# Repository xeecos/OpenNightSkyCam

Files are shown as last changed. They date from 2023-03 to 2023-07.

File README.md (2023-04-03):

# Open Night Sky Cam
Open Night Sky Cam is a long exposure time camera based on ESP32-S3.

## Features
* Based On ESP32-S3-Wroom-1 Module with 8MB Flash and 8MB PSRAM
* Long Exposure Time
* TF card supported by SDMMC or SdFat Library
* U-Disk Mode, USB 2.0 HighSpeed Write and Read Files
* C-Mount, also Support M12 Lens and 1.25 Inch Telescope Mount with adapter
* USB Serial Mode

## Architecture
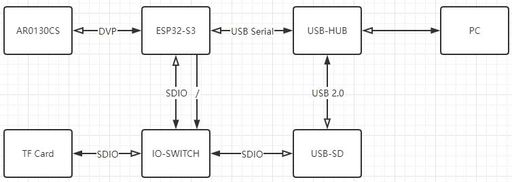
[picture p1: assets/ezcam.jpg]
architecture ezcam_architecture


## PCB
* Main PCB Project: https://oshwlab.com/flashindream/opennightskycam
* Sensor PCB Project: https://oshwlab.com/flashindream/ar0130-dvp
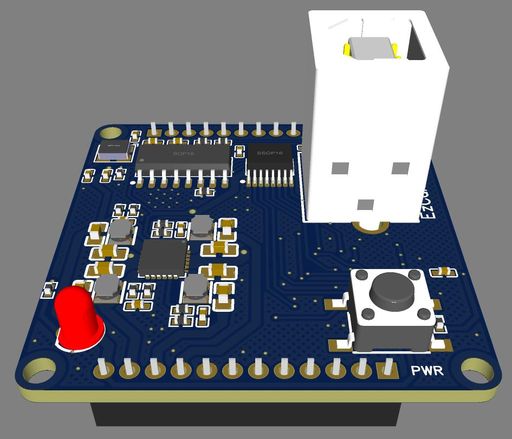
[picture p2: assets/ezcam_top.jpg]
pcb ezcam_top

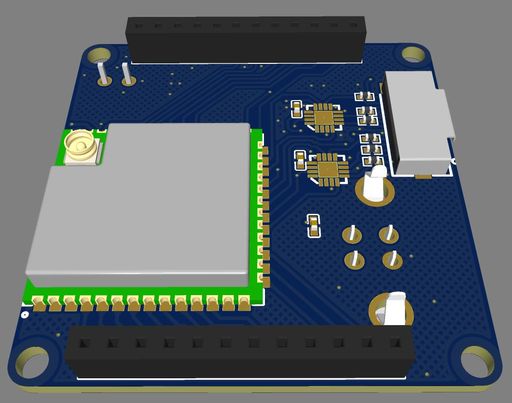
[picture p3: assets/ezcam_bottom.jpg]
pcb ezcam_bottom

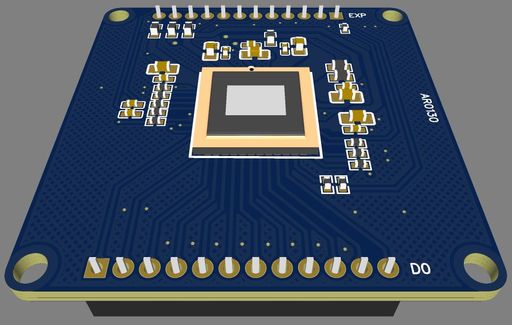
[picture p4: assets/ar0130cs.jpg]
pcb ar0130cs


## Mechanical
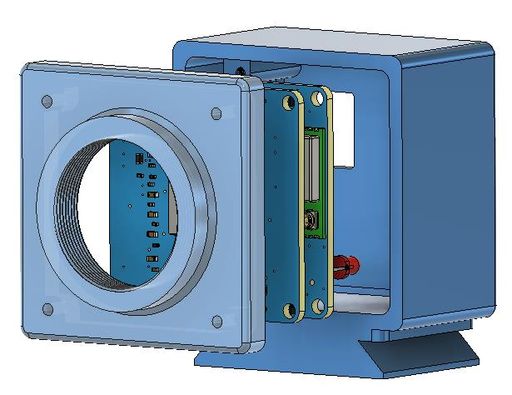
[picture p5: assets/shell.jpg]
shell


## Firmware
* install VSCode and Platformio
* download and open the firmware source code by VSCode
* copy the "esp32-s3-wroom-1.json" to ~/.platformio/platforms/espressif32/boards
* compile the code
* build and upload the filesystem image for web

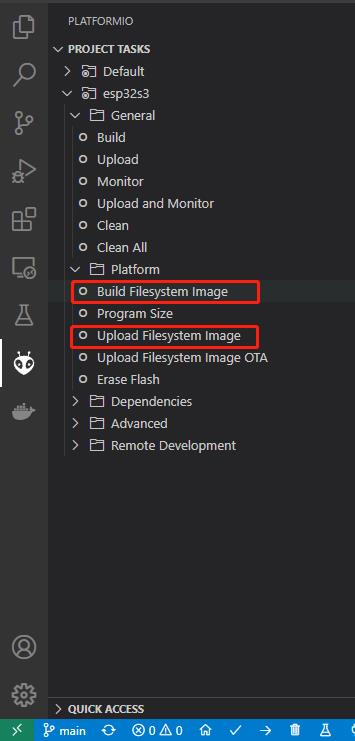
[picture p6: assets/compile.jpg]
compile


## How To Use
* plug in USB cable to the cam.
* connect "Night-Sky" ssid without password by WiFi
* open http://192.168.43.1/index.html on your browser
* close the U-DISK mode on Setting tab
* then preview it 

## Video
* https://www.youtube.com/watch?v=hJdsUjagThk
* https://www.youtube.com/watch?v=0wduta1NCjs
* https://www.youtube.com/watch?v=QMlR2NVDoeQ

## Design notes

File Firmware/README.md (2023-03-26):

# Open Night Sky Cam
# 蓝牙连接
### 查询名称和ip
### 配置WiFi网络
### 修改名称
# WiFi连接
### 查询状态
 * 版本号
 * 任务状态
 * 时间
### 查询SD文件列表
### 获取最新照片
### 设置参数
 * 拍摄参数
 * 时间
### 设置任务
### 开始任务
### 暂停任务
### 继续任务
# OTA升级

### Upload Firmware
esptool.exe --chip esp32s3 --port "COM5" --baud 921600  --before default_reset --after hard_reset write_flash  -z --flash_mode dio --flash_freq 80m --flash_size 8MB 0x0 ".pio//build//esp32s3//bootloader.bin" 0x8000 ".pio//build//esp32s3//partitions.bin" 0x10000 ".pio//build//esp32s3//firmware.bin"

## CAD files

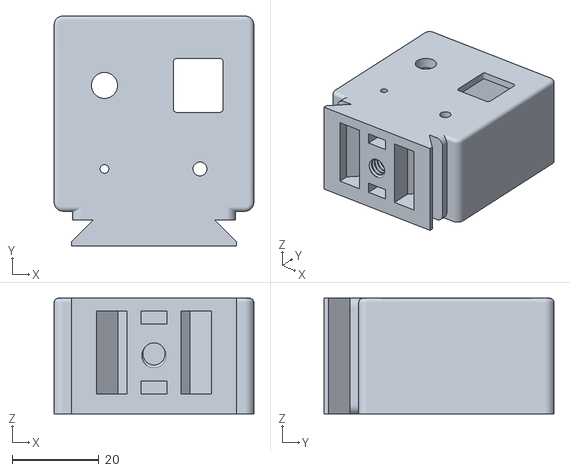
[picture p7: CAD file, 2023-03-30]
Mechanical/bottom.stl
46.0 x 53.0 x 26.7

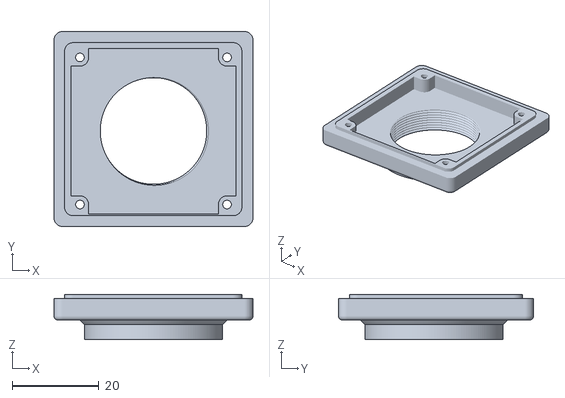
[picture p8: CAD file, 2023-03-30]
Mechanical/top.stl
46.0 x 45.1 x 10.5

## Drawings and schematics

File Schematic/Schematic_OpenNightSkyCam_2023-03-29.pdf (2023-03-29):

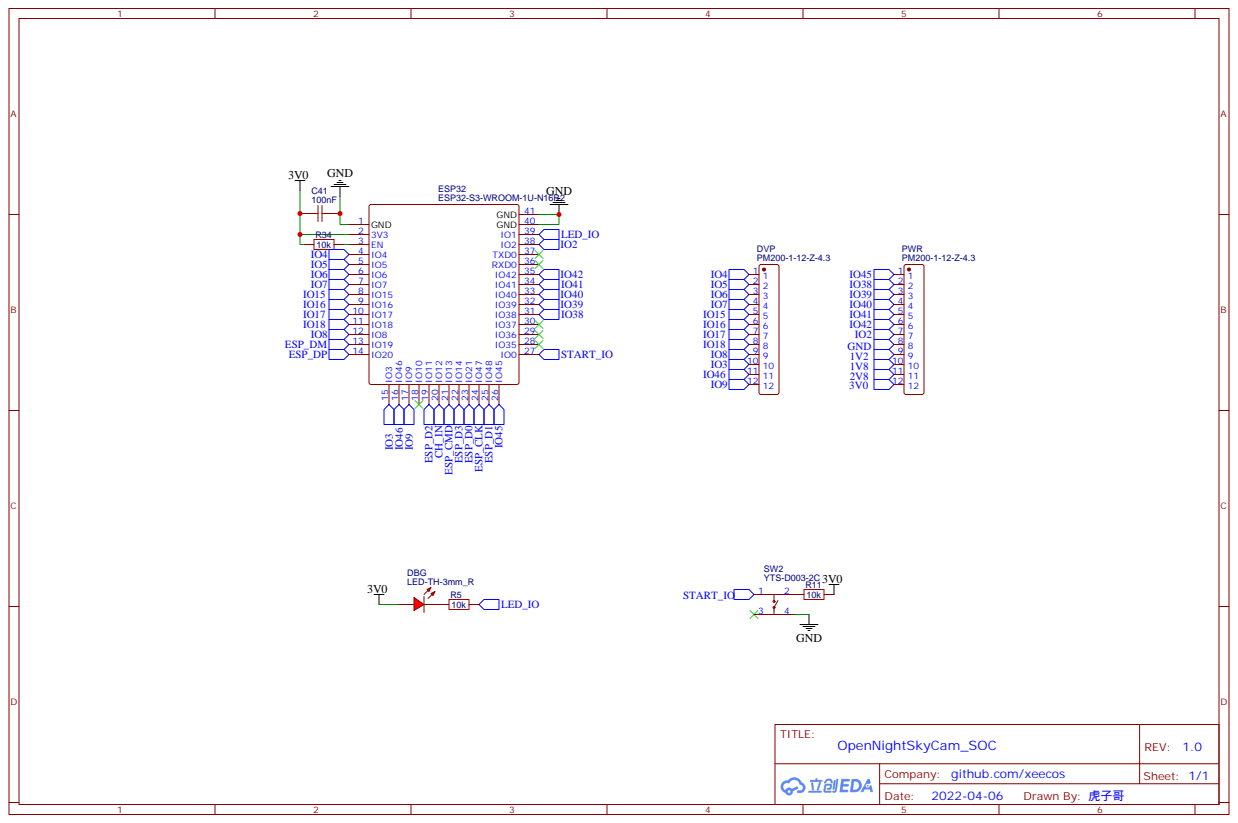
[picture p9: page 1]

Company: github.com/xeecos

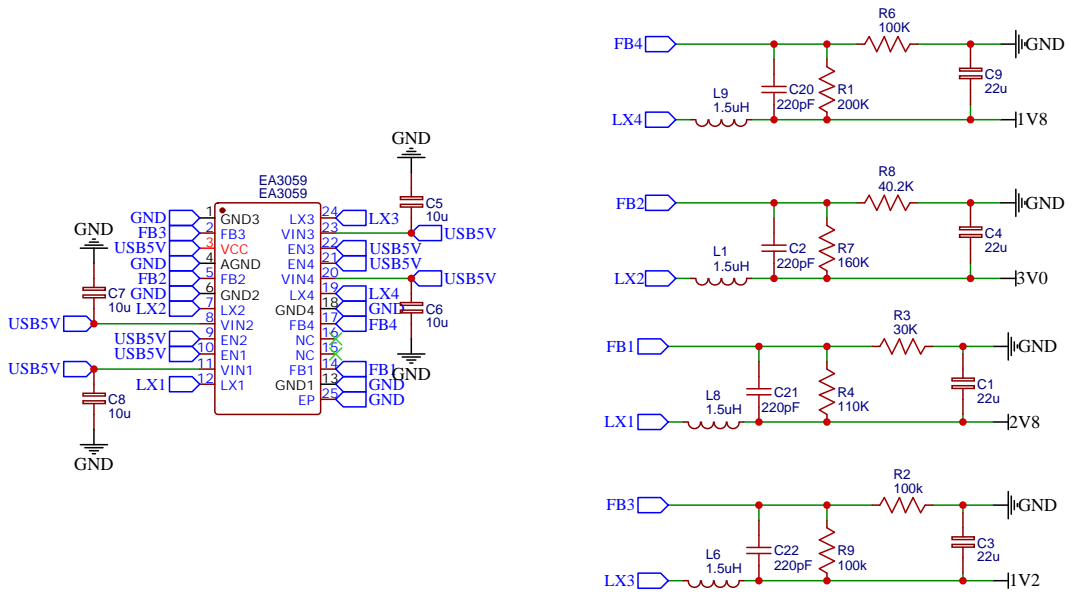
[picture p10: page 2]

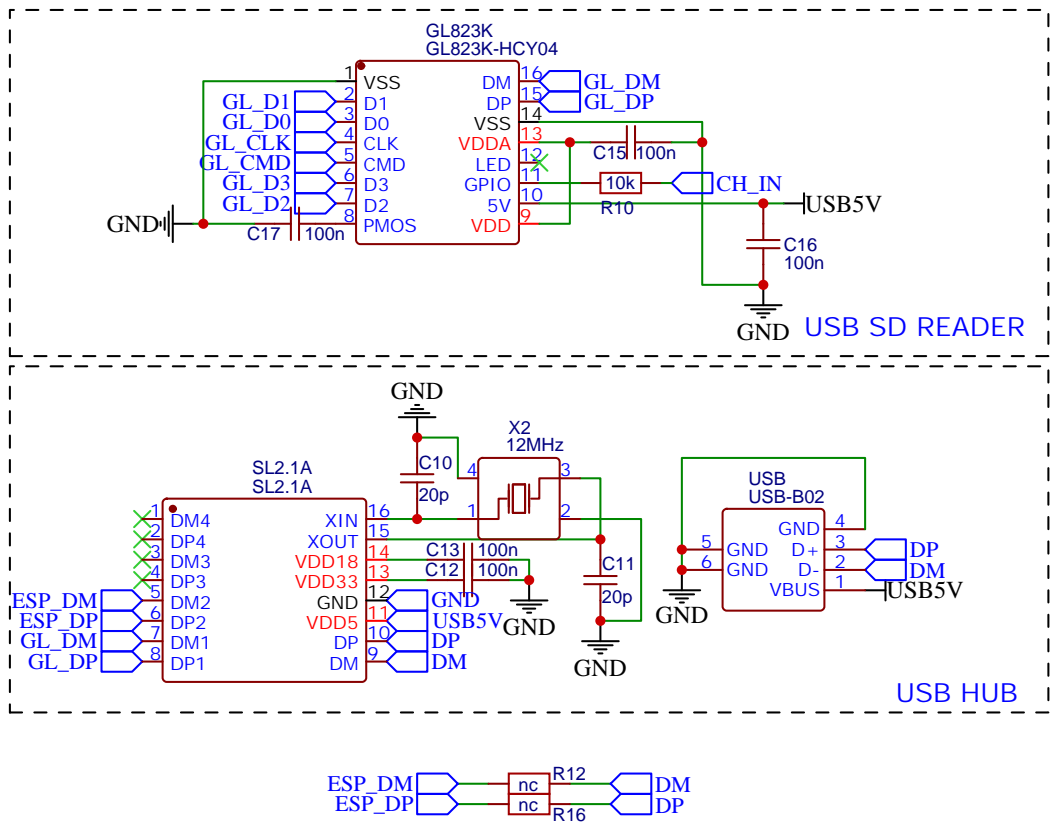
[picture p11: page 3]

GL823K-HCY04
5V 10 GPIO 11 LED 12 VDDA 13 VSS 14 DP 15 DM 16

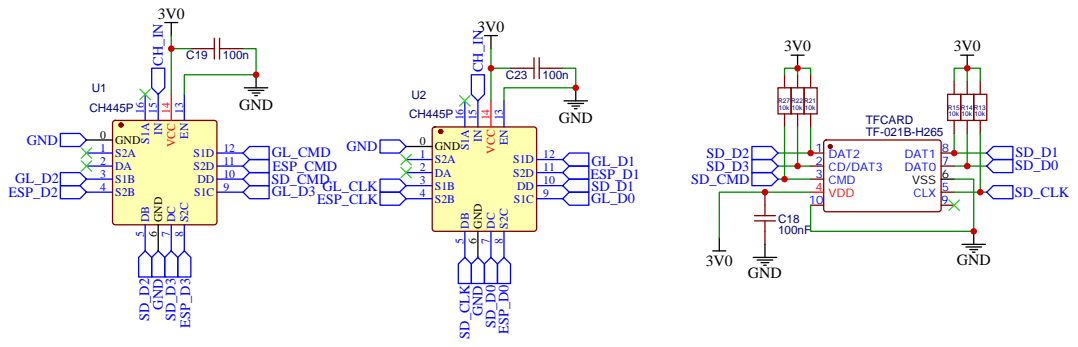
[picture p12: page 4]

EN 13 VCC 14 IN 15 S1A 16 CH_IN GND

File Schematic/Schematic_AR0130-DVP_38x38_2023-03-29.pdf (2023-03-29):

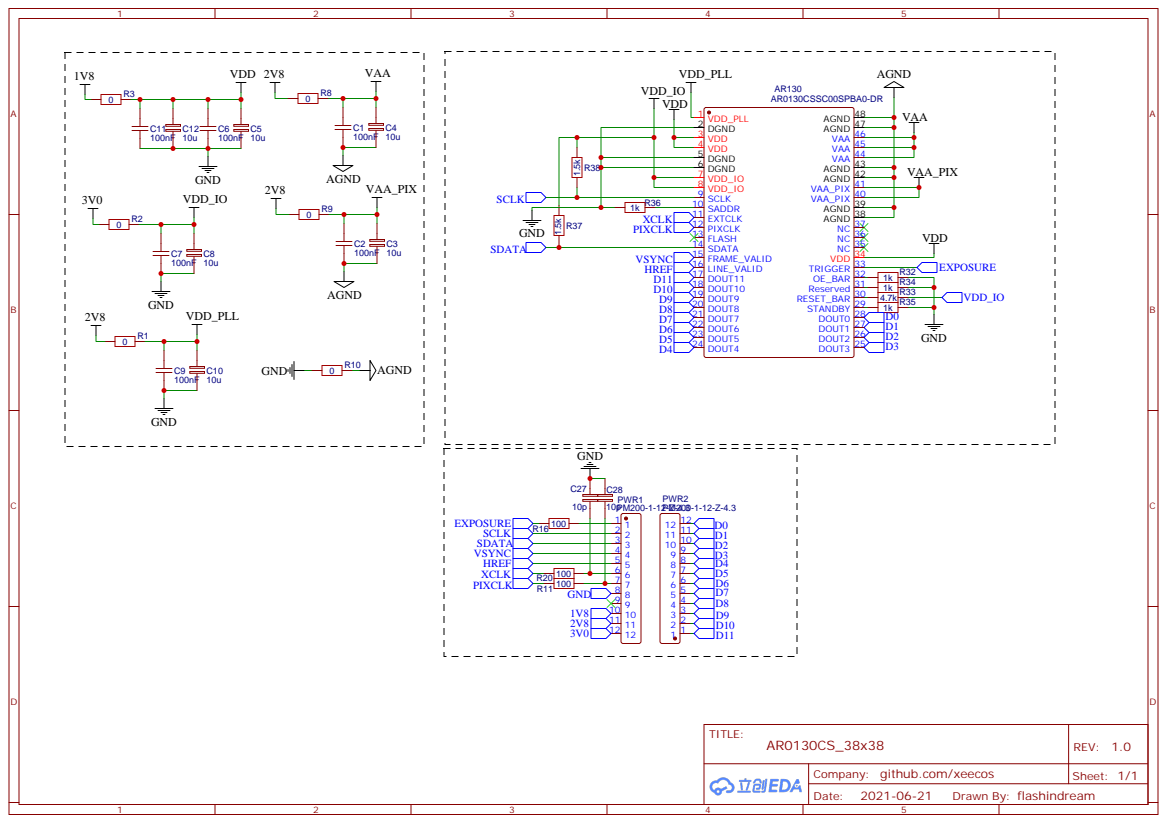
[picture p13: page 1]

Company: github.com/xeecos

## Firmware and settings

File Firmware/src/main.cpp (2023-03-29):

#include <Arduino.h>
#include "log.h"
#include "ble.h"
#include "global.h"
#include "service.h"
#include "capture.h"
#include "tf.h"
#include "task.h"
#include "config.h"
void setup()
{
    LOG_INIT(921600);
    USBSerial.setDebugOutput(false);
    tf_unmount();
    global_init();
    #ifdef BT_ENABLED
    ble_init();
    #endif
    service_init();
    capture_init();
    task_init();
}
void loop()
{
    global_run();
    #ifdef BT_ENABLED
    ble_run();
    #endif
    service_run();
    task_run();
    capture_run();
}

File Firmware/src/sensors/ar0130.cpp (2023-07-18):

#include "ar0130.h"
#include "xclk.h"
#include "config.h"
#include <stdio.h>
#include "sccb.h"
#include "global.h"
#include <Arduino.h>
#include "xclk.h"
#include "log.h"
#include "capture.h"
#include "service.h"
#include <stdint.h>

uint16_t ar0130_default_regs[120][2] = {
	{0x301A, 0x0001},
	{0x301A, 0b1000111011100},
	{0x3044, 0x0400},
	{0x3064, 0b1100110000010}, // DISABLE EMB. DATA
	{0x309E, 0x0000},		   // DCDS_PROG_START_ADDR
	{0x30E4, 0x6372},		   // ADC_BITS_6_7
	{0x30E2, 0x7253},		   // ADC_BITS_4_5
	{0x30E0, 0x5470},		   // ADC_BITS_2_3
	{0x30E6, 0xC4CC},		   // ADC_CONFIG1
	{0x30E8, 0x8050},		   // ADC_CONFIG2
	{0x3082, 0x0029},		   // OP MODE CTL
	{0x301E, 0x00C8},		   // DATA_PEDESTAL
	{0x3EDE, 0xC005},		   // DAC_LD_18_19
	{0x3EE2, 0xA46B},		   // DAC_LD_22_23
	{0x3EE0, 0x047D},		   // DAC_LD_20_21
	{0x3EDC, 0x0070},		   // DAC_LD_16_17
	{0x3EE6, 0x4303},		   // DAC_LD_26_27
	{0x3EE4, 0xD208},		   // DAC_LD_24_25
	{0x3ED6, 0x00BD},		   // DAC_LD_10_11
	{0x30EA, 0b110000000000},  // Black Level Correction
	{0x3044, 0b10000000000},	  // Row-wise Noise Correction
	{0x30D4, 0b1110000000000111}, // COLUMN_CORRECTION
	{0x3002, 0x0000},			  // Y_ADDR_START = 2
	{0x3004, 0x0000},			  // X_ADDR_START = 0
	{0x3006, 0x03C0},			  // Y_ADDR_END
	{0x3008, 0x04FF},			  // X_ADDR_END = 1279
	{0x300A, 0x03DE},			  // Vertical blanking / FRAME_LENGTH_LINES
	{0x300C, 0x0596},			  // Horizontal blanking / LINE_LENGTH_PCK = 1650
	{0x3100, 0x0003},
	// {0x31D0, 0x0003},			  // HDR_COMP
	{0x302C, 6},				  // P1=1~16 VT_SYS_CLK_DIV
	{0x302A, 8},				  // P2=4~16 VT_PIX_CLK_DIV
	{0x302E, 6},				  // N=1~63 PRE_PLL_CLK_DIV
	{0x3030, 32},				  // M=32~255 PLL_MULTIPLIER
	{0x3032, 0x0},				  // binning = 00x3056, gain_level & 0xff);
	{0x30B0, 0x1300 | 0b1000100}, // M=32~255 PLL_MULTIPLIER
								  // // XCLK=2MHz<freq/N<24MHz
								  // // fPIXCLK= (fEXTCLK × M) / (N × P1 x P2)
								  // // fPIXCLK= (16*32)/(4*8*4)
	{0x3070, 0x0000},			  // test pattern
	{0x306E, 0},
	{0x311C, 0xFFFF},			  // AE_MAX_EXPOSURE_REG
	{0x311E, 0x0001},			  // AE_MIN_EXPOSURE_REG
	{0x3EDA, 0x0F03}, // DAC_LD_14_15
	{0x3ED8, 0x01EF}, // DAC_LD_12_13
	{0, 0}};

bool status;
long _time = -1;
int _vblank;
int _hblank;
int _black;
int _width;
int _height;
int _gain;
int _xclk;
int xres, yres;
int exp_pin;

long ar0130_get_coarse()
{
	return global_get_coarse();
}

uint16_t ar0130_read16(uint16_t cmd)
{
	return 0; //_sccb->read16(cmd);
}
void ar0130_standby(bool enabled)
{
	if (!enabled)
	{
		// SCCB_Write16_16(0x301A, 0b1100111011110);
		// SCCB_Write16_16(0x301A, 0b1100011011110);
		// SCCB_Write16_16(0x301A, 0x10DC);
		// digitalWrite(EXPOSURE,HIGH);
	}
	else
	{
		// SCCB_Write16_16(0x301A, 0x10D8);
		// SCCB_Write16_16(0x301A, 0b1100111011100);
		// SCCB_Write16_16(0x301A, 0b0100111011100);
		// SCCB_Write16_16(0x301A, 0b1100111011000);
		// digitalWrite(EXPOSURE,LOW);
	}
}

static int get_reg(sensor_t *sensor, int reg, int mask)
{
	int ret = SCCB_Read16_16(sensor->slv_addr, reg & 0xFFFF);
	if (ret > 0)
	{
		ret &= mask;
	}
	return ret;
}

static int set_reg(sensor_t *sensor, int reg, int mask, int value)
{
	int ret = 0;
	ret = SCCB_Read16_16(sensor->slv_addr, reg & 0xFFFF);
	if (ret < 0)
	{
		return ret;
	}
	value = (ret & ~mask) | (value & mask);
	ret = SCCB_Write16_16(sensor->slv_addr, reg & 0xFFFF, value);
	return ret;
}

static int set_reg_bits(sensor_t *sensor, uint16_t reg, uint8_t offset, uint8_t length, uint8_t value)
{
	int ret = 0;
	ret = SCCB_Read16_16(sensor->slv_addr, reg);
	if (ret < 0)
	{
		return ret;
	}
	uint16_t mask = ((1 << length) - 1) << offset;
	value = (ret & ~mask) | ((value << offset) & mask);
	ret = SCCB_Write16_16(sensor->slv_addr, reg & 0xFFFF, value);
	return ret;
}

static int get_reg_bits(sensor_t *sensor, uint16_t reg, uint8_t offset, uint8_t length)
{
	int ret = 0;
	ret = SCCB_Read16_16(sensor->slv_addr, reg);
	if (ret < 0)
	{
		return ret;
	}
	uint8_t mask = ((1 << length) - 1) << offset;
	return (ret & mask) >> offset;
}

static int reset(sensor_t *sensor)
{
	int i = 0;
	const uint16_t(*regs)[2];
	#ifdef EXPOSURE
	pinMode(EXPOSURE, OUTPUT);
	digitalWrite(EXPOSURE, LOW);
	#endif
	// Write default regsiters
	for (i = 0, regs = ar0130_default_regs; regs[i][0]; i++)
	{
		SCCB_Write16_16(sensor->slv_addr, regs[i][0], regs[i][1]);
		vTaskDelay(10 / portTICK_PERIOD_MS);
	}

	// SCCB_Write16_16(sensor->slv_addr,0x3112, 0x029F); // AE_DCG_EXPOSURE_HIGH_REG
	// 	vTaskDelay(10 / portTICK_PERIOD_MS);
	// SCCB_Write16_16(sensor->slv_addr,0x3114, 0x0001); // AE_DCG_EXPOSURE_LOW_REG
	// 	vTaskDelay(10 / portTICK_PERIOD_MS);
	// SCCB_Write16_16(sensor->slv_addr,0x3116, 0x02C0); // AE_DCG_GAIN_FACTOR_REG
	// 	vTaskDelay(10 / portTICK_PERIOD_MS);
	// SCCB_Write16_16(sensor->slv_addr,0x3118, 0x005B); // AE_DCG_GAIN_FACTOR_INV_REG
	// 	vTaskDelay(10 / portTICK_PERIOD_MS);
	// SCCB_Write16_16(sensor->slv_addr,0x3102, 800); // AE_LUMA_TARGET_REG
	// 	vTaskDelay(10 / portTICK_PERIOD_MS);
	// SCCB_Write16_16(sensor->slv_addr,0x3104, 0x1000); // AE_HIST_TARGET_REG
	// 	vTaskDelay(10 / portTICK_PERIOD_MS);
	// SCCB_Write16_16(sensor->slv_addr,0x3108, 16);     // ae_min_ev_step_reg
	// 	vTaskDelay(10 / portTICK_PERIOD_MS);
	// SCCB_Write16_16(sensor->slv_addr,0x310A, 2);     // ae_max_ev_step_reg
	// 	vTaskDelay(10 / portTICK_PERIOD_MS);
	// SCCB_Write16_16(sensor->slv_addr,0x3124, 0x7FFF); // AE_ALPHA_V1_REG
	// 	vTaskDelay(10 / portTICK_PERIOD_MS);
	// SCCB_Write16_16(sensor->slv_addr,0x3126, 0x0080); // AE_ALPHA_V1_REG
	// 	vTaskDelay(10 / portTICK_PERIOD_MS);
	return 0;
}

static int set_pixformat(sensor_t *sensor, pixformat_t pixformat)
{
	int ret = 0;
	sensor->pixformat = pixformat;

	switch (pixformat)
	{
	case PIXFORMAT_RAW:
		// set_reg_bits(sensor, 0x12, 0, 3, 0x4);
		return ret;
		break;
	default:
		return -1;
	}

	// Delay
	vTaskDelay(30 / portTICK_PERIOD_MS);

	return ret;
}

static int set_framesize(sensor_t *sensor, framesize_t framesize)
{
	int ret = 0;
	uint16_t w = resolution[framesize].width;
	uint16_t h = resolution[framesize].height;

	SCCB_Write16_16(sensor->slv_addr, 0x3006, sensor->status.vstart + h - 1); // Y_ADDR_END
	SCCB_Write16_16(sensor->slv_addr, 0x3008, sensor->status.hstart + w - 1); // X_ADDR_END = 1279
	sensor->status.framesize = framesize;
	// Delay
	vTaskDelay(30 / portTICK_PERIOD_MS);

	return ret;
}
static int set_vstart(sensor_t *sensor, uint16_t vstart)
{
	int ret = 0;
	SCCB_Write16_16(sensor->slv_addr, 0x3002, vstart); // Y_ADDR_START = 2
	sensor->status.vstart = vstart;
	// Delay
	vTaskDelay(30 / portTICK_PERIOD_MS);

	return ret;
}

static int set_hstart(sensor_t *sensor, uint16_t hstart)
{
	int ret = 0;
	SCCB_Write16_16(sensor->slv_addr, 0x3004, hstart); // X_ADDR_START = 0
	sensor->status.hstart = hstart;
	// Delay
	vTaskDelay(30 / portTICK_PERIOD_MS);

	return ret;
}
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

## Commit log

2023-03-27 add lang switch
2023-03-29 add led show
2023-03-30 add 3d stl
